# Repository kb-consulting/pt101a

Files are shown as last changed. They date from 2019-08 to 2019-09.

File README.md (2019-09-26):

# LPA96 - 96 Well Light Plate Apparatus (LPA) PCB
### Derived from original Tabor Lab designs from Rice University, with thermal and other improvements
This version uses a single blue LED for each of the 96 wells, and aims to solve the thermal problems with the TaborLab 96well design (dual LED per well), which was itself derived from the original 24well design (The latest 24well design has since diverged, to what is now available on GitHub).  
This version has been redesigned by Kevin Bibby (https://www.linkedin.com/in/kevinbibby/), commissioned by Dr Jenny Molloy - University of Cambridge / Cambridge Open Bioeconomy Lab.  
  
Original 24well article: https://www.nature.com/articles/srep35363  
Latest 24well Github (including chassis and other firmware files): https://github.com/taborlab/LPA-hardware  

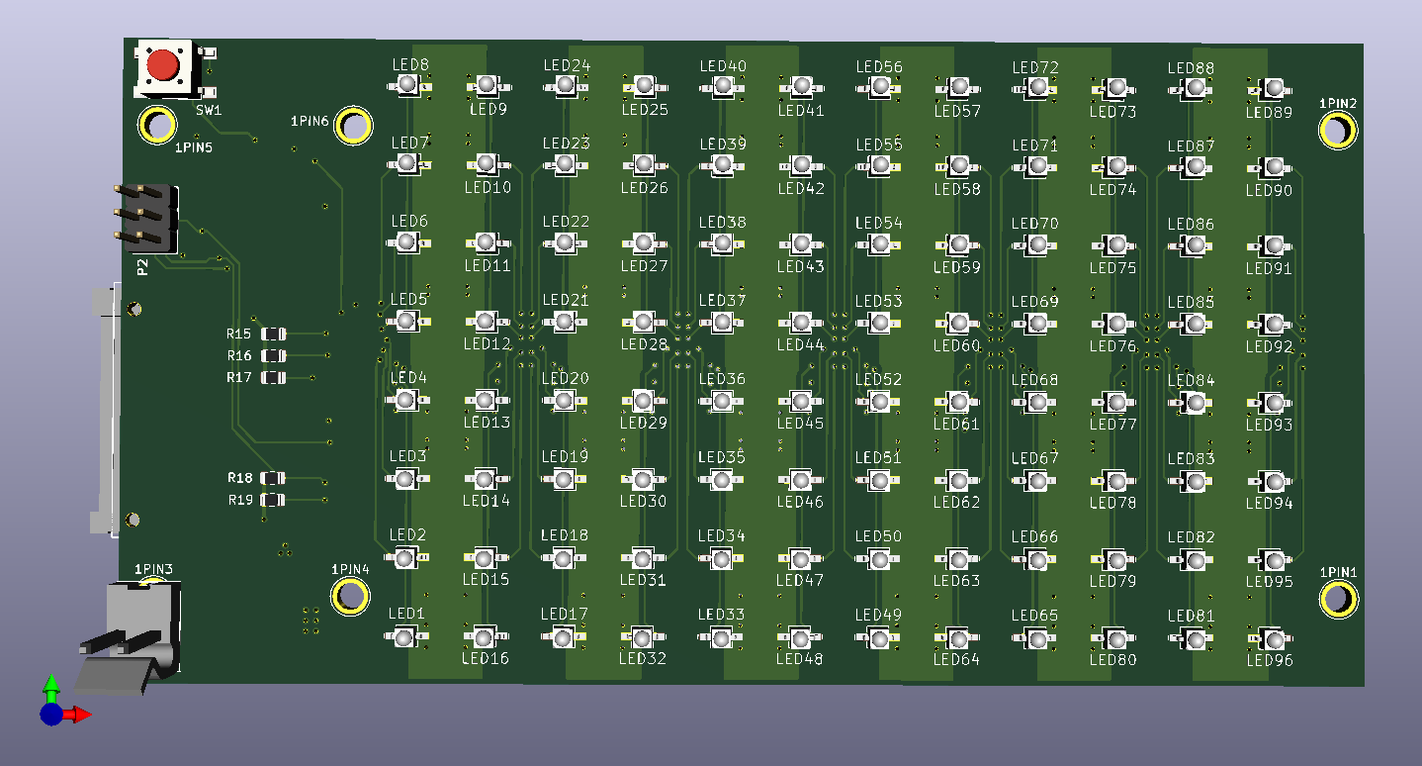
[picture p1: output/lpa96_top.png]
PCB TOP

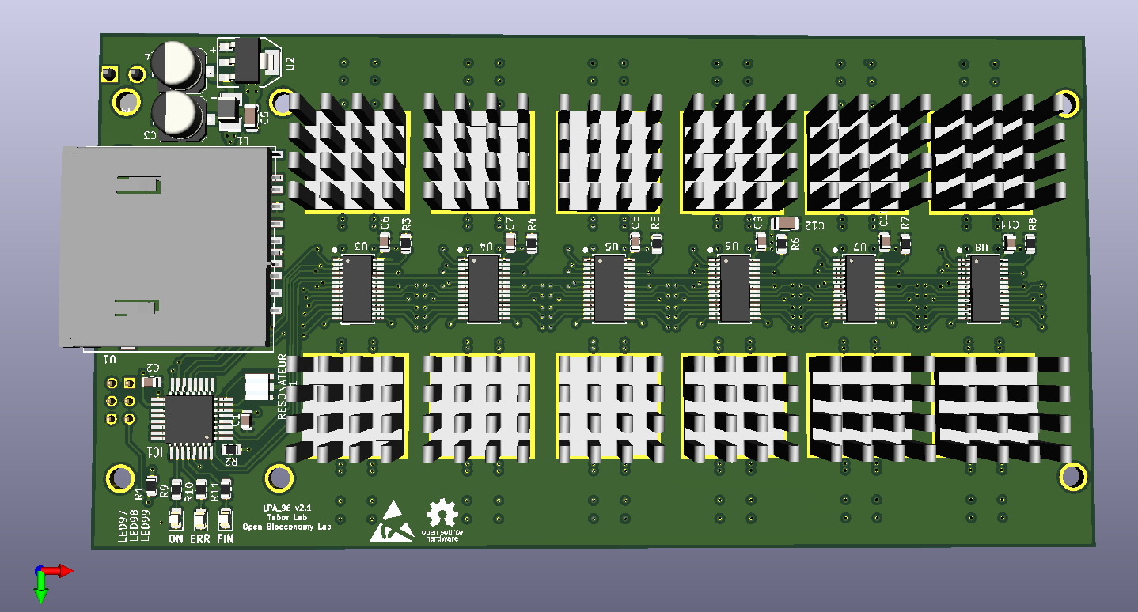
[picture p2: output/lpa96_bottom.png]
PCB BOTTOM


LPA96 v2.1  
05/09/2019 Kevin Bibby  
-------------------------
- Added all part info from original 24well LPA 'Nature' article (Supplementary Information, Table S1).
- Part info uses "Description", "Manufacturer1", "MPN1", "Vendor1" and "SKU1" part fields in KiCAD.
- Added files necessary to work with Kitspace.org for sharing the design and ordering parts easily.
- changed BOM info to reflect new LED chosen for this 96well version
- changed BOM info for C5,C12 - chosen part for new 1206 case size (was 0805 in v1.1).
- changed P2 to 2x3way exact part (2x3way) rather than 40way breakable header.
- changed R15-R19 from 50k to 47k to match part in BOM
- changed P1 and P2 library part 3D models to match part from BOM
- Note: P1 fouls on nearby hole, issue from original LPA96 design only just discovered after correct part info added
- Fixed U2 SOT223 3D model to use modern STEP model instead of old .wrl
- Updated footprints to use KiCAD5 latest (some changed since v2.0 e.g. rounded rectangle pads for commodity C / R footprints)

LPA96 v2.0  
22/08/2019 Kevin Bibby  
-------------------------
- changed to 4-layer PCB, and thermal improvements throughout, uses top planes and internal IN3 layer for VIN LED thermal dissipation, BOTTOM layer for GND LED driver IC dissipation
- changed from dual LEDs to single LEDs (VLDx1232G), and reduced the number of LED drivers accordingly from 12 to 6
- LED1-LED96 placed for zig-zag left-right pattern starting in bottom left of grid
- renamed all files from tca to lpa96, and set schematic/layout titleblocks accordingly incl author names
- resolved library issues and rescued parts, removed obsolete library parts - all parts are now either from default KiCAD5 libraries or from included project libraries
- fixed all ERC and DRC (Electrical/Design Rule Check) errors, through various means incl component/pin tweaks
- added 3D models for all parts (some estimates/representative due to source BOM not being available, P1 especially)
- added example 14x14x14mm heatsink footprint to library & STEP model and added to board to improve 3D CAD output / render
- renamed R_ON1,R_ERR1,R_FIN1 as R9,R10,R11 (best practice)
- renamed RESET1 as SW1 and ON1,ERR1,FIN1 as LED97,LED98,LED99 (best practice)
- changed C5 from 0805 to 1206 case size (better for 10uF), and added second of same bulk cap C12 for VCC on LED driver page, placed near LED drivers
- added OSHW and ESD logos to board
- moved P2 away from hole
- changed name of pin8/9 from "RSV" to DAT1/DAT2 to match datasheet of guessed part
- changed pin4 of regulator U2 manually to VCC net as symbol not made to include pin4
- added copper keepout around resonator Y1
- changed keepout near SDCARD to apply to copper planes too
- changed footprint for TLC5941 (downloaded from TI official, via ultralibrarian, generated for IPC 'most'), plus changed pin29 (pad) to be solid connection
- added pin29 for thermal pad to TLC5941 symbol (to match new footprint) and connected to GND
- changed via size from 0.889mm/0.653mm to 0.8mm/0.4mm , better annular ring margin and more space for routing while still being plenty manufacturable
- added soldermask 15mm squares to expose copper for 14mm heatsinks
- added heading/annotation text on schematic page

LPA96 v1.1 ?? (previously called 'TCA96')
-------------------------
Version received at handover. Had thermal issues to resolve and required a change of LEDs and reduction of driver ICs.

LPA96 v1.0 ??
-------------------------
??

 LPA96 / 'TCA96' previously derived from original 24-well version.

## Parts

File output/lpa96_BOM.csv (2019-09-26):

Source: | C:\freelance\git\pt101a\lpa96.sch
Date: | 05/09/2019 13:12:48
Tool: | Eeschema (5.1.4)-1
Generator: | C:\freelance\git\common-kicad/bom_csv_grouped_by_MPN.py
Component Count: | 141
Collated Components:
Item | Qty | Reference(s) | Value | Description | Manufacturer | MPN | Vendor | SKU | Symbol | Footprint | Datasheet
1 | 8 | C1, C2, C6, C7, C8, C9, C10, C11 | 100nF | -20/+80% 50V Y5V SMD MLCC Capacitor 0805 | Samsung | CL21F104ZBCNNNC | Digikey | 1276-1007-1-ND | Device:C | Capacitor_SMD:C_0805_2012Metric | ~
2 | 2 | C3, C4 | 47uF | 20% 35V SMD Electrolytic Capacitor | Nichicon | UWT1V470MCL1GS | Digikey | 493-2202-1-ND | Device:C | lpa96_footprints:CP_Elec_6.3x5.3 | ~
3 | 2 | C5, C12 | 10uF | 10% 25V X5R SMD MLCC Capacitor 1206 | Samsung | CL31A106KAHNNNE | Digikey | 1276-1075-1-ND | Device:C | Capacitor_SMD:C_1206_3216Metric | ~
4 | 1 | IC1 | ATMEGA328-A | AVR ATmega Microcontroller IC 8-Bit 20MHz | Microchip | ATMEGA328-AU | Digikey | ATMEGA328-AU-ND | lpa96_symbols:ATMEGA328-A | lpa96_footprints:TQFP32_FIXED
5 | 1 | L1 | 10uH | Wirewound Chip Inductor 900mA 1210 | Kemet | L1210R100MDWIT | Digikey | 399-9595-1-ND | Device:L | lpa96_footprints:L-1210 | ~
6 | 96 | LED1, LED2, LED3, LED4, LED5, LED6, LED7, LED8, LED9, LED10, LED11, LED12, LED13, LED14, LED15, LED16, LED17, LED18, LED19, LED20, LED21, LED22, LED23, LED24, LED25, LED26, LED27, LED28, LED29, LED30, LED31, LED32, LED33, LED34, LED35, LED36, LED37, LED38, LED39, LED40, LED41, LED42, LED43, LED44, LED45, LED46, LED47, LED48, LED49, LED50, LED51, LED52, LED53, LED54, LED55, LED56, LED57, LED58, LED59, LED60, LED61, LED62, LED63, LED64, LED65, LED66, LED67, LED68, LED69, LED70, LED71, LED72, LED73, LED74, LED75, LED76, LED77, LED78, LED79, LED80, LED81, LED82, LED83, LED84, LED85, LED86, LED87, LED88, LED89, LED90, LED91, LED92, LED93, LED94, LED95, LED96 | LED_ALT | Blue 465nm LED 3V 2-SMD, Gull Wing | Vishay | VLDB1232G-08 | Digikey | VLDB1232G-08CT-ND | Device:LED_ALT | lpa96_footprints:VLDx1232G | ~
7 | 1 | LED97 | LED_ALT | SMD LED Green 0805 | OSRAM | LG R971-KN-1 | Digikey | 475-1410-1-ND | Device:LED_ALT | LED_SMD:LED_0805_2012Metric | ~
8 | 1 | LED98 | LED_ALT | SMD LED Red 0805 | OSRAM | LH R974-LP-1 | Digikey | 475-1415-1-ND | Device:LED_ALT | LED_SMD:LED_0805_2012Metric | ~
9 | 1 | LED99 | LED_ALT | SMD LED Yellow 0805 | OSRAM | LY R976-PS-36 | Digikey | 475-2560-1-ND | Device:LED_ALT | LED_SMD:LED_0805_2012Metric | ~
10 | 1 | P1 | CONN_2 | Connector Male Through Hole 2 position 0.156" (3.96mm) | Molex | 0009652028 | Digikey | WM18823-ND | lpa96_symbols:CONN_2 | lpa96_footprints:PIN_ARRAY_2X1_3960um
11 | 1 | P2 | CONN_3X2 | Header Through Hole 2x3way 6 position 0.1" (2.54mm) | Amphenol ICC | 67997-206HLF | Digikey | 609-3234-ND | lpa96_symbols:CONN_3X2 | lpa96_footprints:pin_array_3x2
12 | 2 | R1, R2 | 10k | 5% Chip Resistor 0805 | Panasonic | ERJ-6GEYJ103V | Digikey | P10KACT-ND | Device:R | Resistor_SMD:R_0805_2012Metric | ~
13 | 6 | R3, R4, R5, R6, R7, R8 | 2.2k | 0.5% Chip Resistor 0805 | Susumu | RR1220P-222-D | Digikey | RR12P2.2KDCT-ND | Device:R | Resistor_SMD:R_0805_2012Metric | ~
14 | 3 | R9, R10, R11 | 330R | 5% Chip Resistor 0805 | Samsung | RC2012J331CS | Digikey | 1276-5519-1-ND | Device:R | Resistor_SMD:R_0805_2012Metric | ~
15 | 5 | R15, R16, R17, R18, R19 | 47k | 5% Chip Resistor 0805 | Panasonic | ERJ-6GEYJ473V | Digikey | P47KACT-ND | Device:R | Resistor_SMD:R_0805_2012Metric | ~
16 | 1 | SW1 | SW_PUSH | SPST-NO Top Activated SMD Tactile Switch | C&K | PTS645SK43SMTR92 LFS | Digikey | CKN9084CT-ND | lpa96_symbols:SW_PUSH | lpa96_footprints:SW_PUSH_SMD | ~
17 | 1 | U1 | SD_CARD | 9 Position Connector SD Card, Surface Mount, Right Angle | Amphenol ICC | 101-00313-68-02 | Digikey | 101-00313-68-02CT-ND | lpa96_symbols:SD_CARD | lpa96_footprints:SD_CONN
18 | 1 | U2 | LD1117S33 | IC Linear Regulator 3.3V 800mA SOT-223 | ST Microelectronics | LD1117S33TR | Digikey | 497-1242-1-ND | lpa96_symbols:LD1117S50 | lpa96_footprints:SOT223 | ~
19 | 6 | U3, U4, U5, U6, U7, U8 | TLC5941 | LED Driver IC 16 Output 28-HTSSOP | Texas Instruments | TLC5941PWP | Digikey | 296-18617-5-ND | lpa96_symbols:TLC5941 | lpa96_footprints:TLC5941_PWP_28 | DOCUMENTATION
20 | 1 | Y1 | RESONATEUR | 16MHz Ceramic Resonator SMD | Abracon | AWSCR-16.00CV-T | Digikey | 535-10008-1-ND | lpa96_symbols:RESONATEUR | lpa96_footprints:crystal_smd

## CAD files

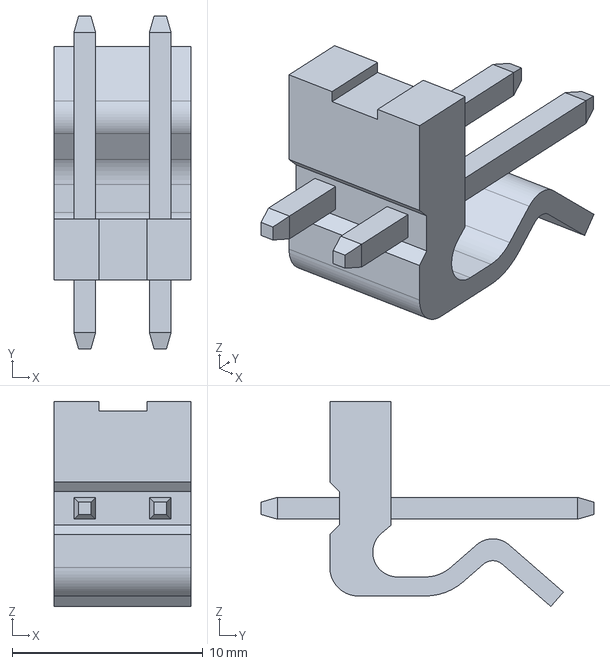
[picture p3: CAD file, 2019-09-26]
footprints/3d-models/Molex_009652028.stp
7.16 x 17.4 x 10.8 mm

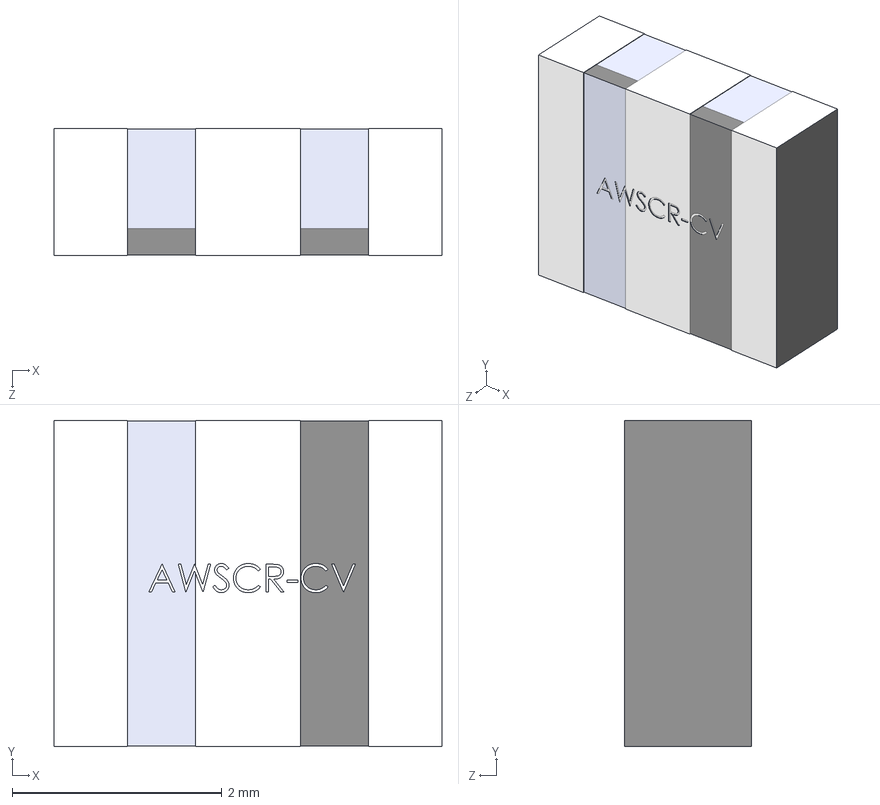
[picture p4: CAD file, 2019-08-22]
footprints/3d-models/example_resonator.step
3.70 x 3.11 x 1.21 mm

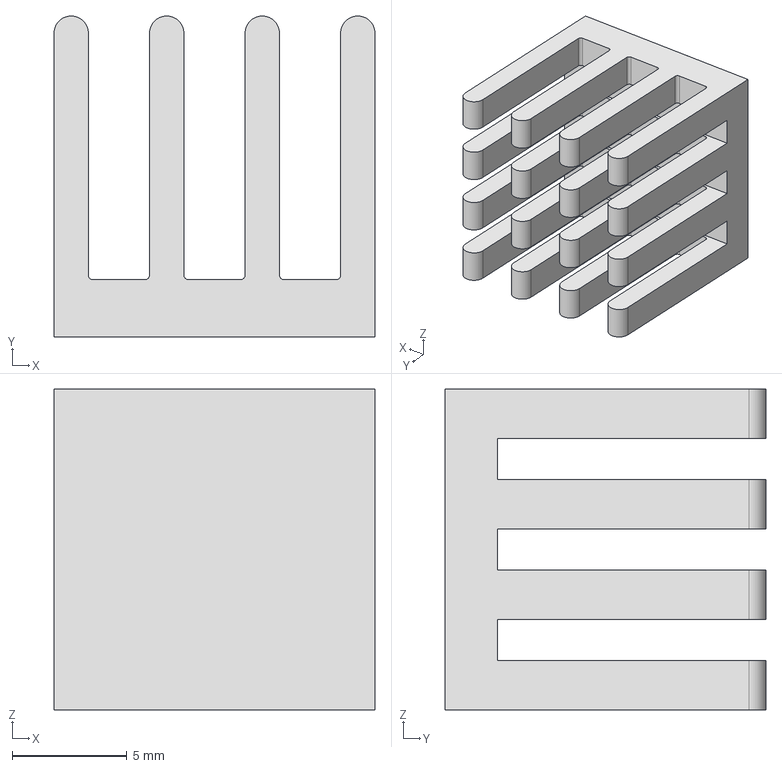
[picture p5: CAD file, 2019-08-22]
footprints/3d-models/example_heatsink_14x14x14mm.stp
14.0 x 14.0 x 14.0 mm

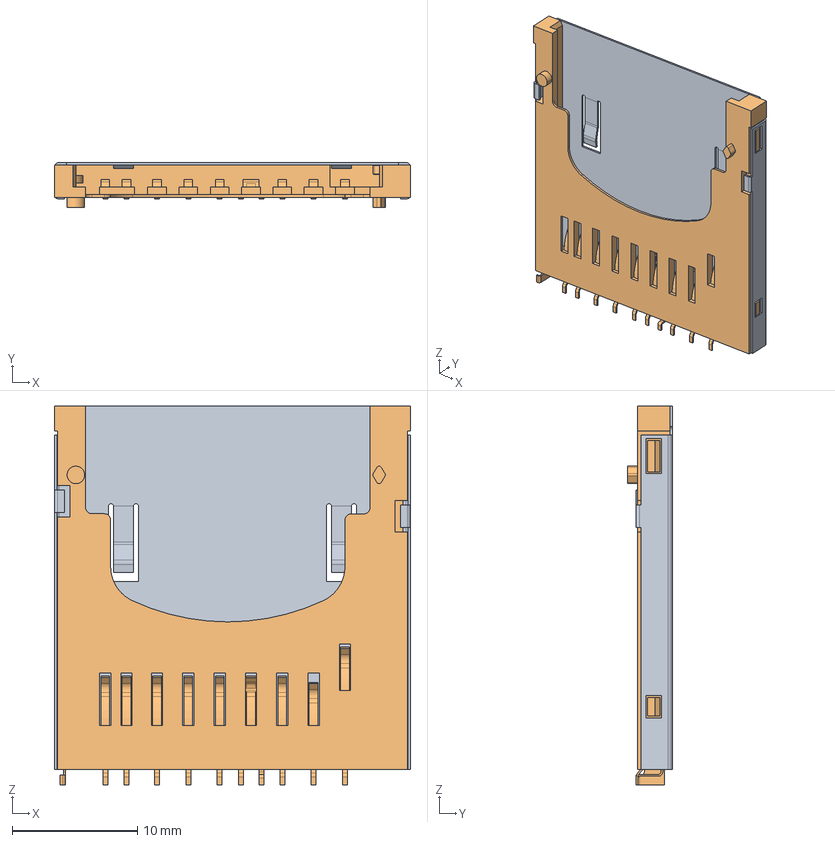
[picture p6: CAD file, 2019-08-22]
footprints/3d-models/SD_card_reader_10067847-001RLF.step
28.4 x 3.60 x 30.3 mm
PRT0003
PRT0005

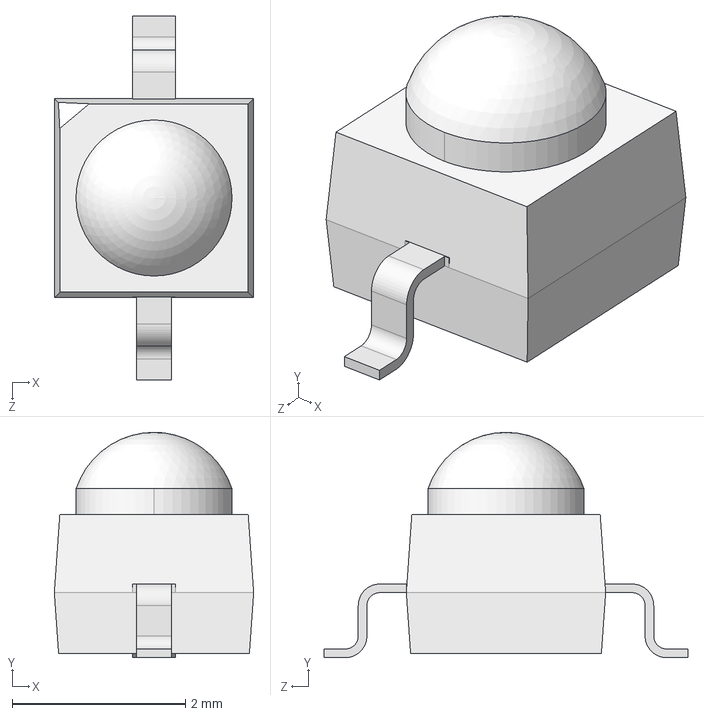
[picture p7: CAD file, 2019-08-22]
footprints/3d-models/smd_led_VLDx1535G.step
2.30 x 2.60 x 4.20 mm

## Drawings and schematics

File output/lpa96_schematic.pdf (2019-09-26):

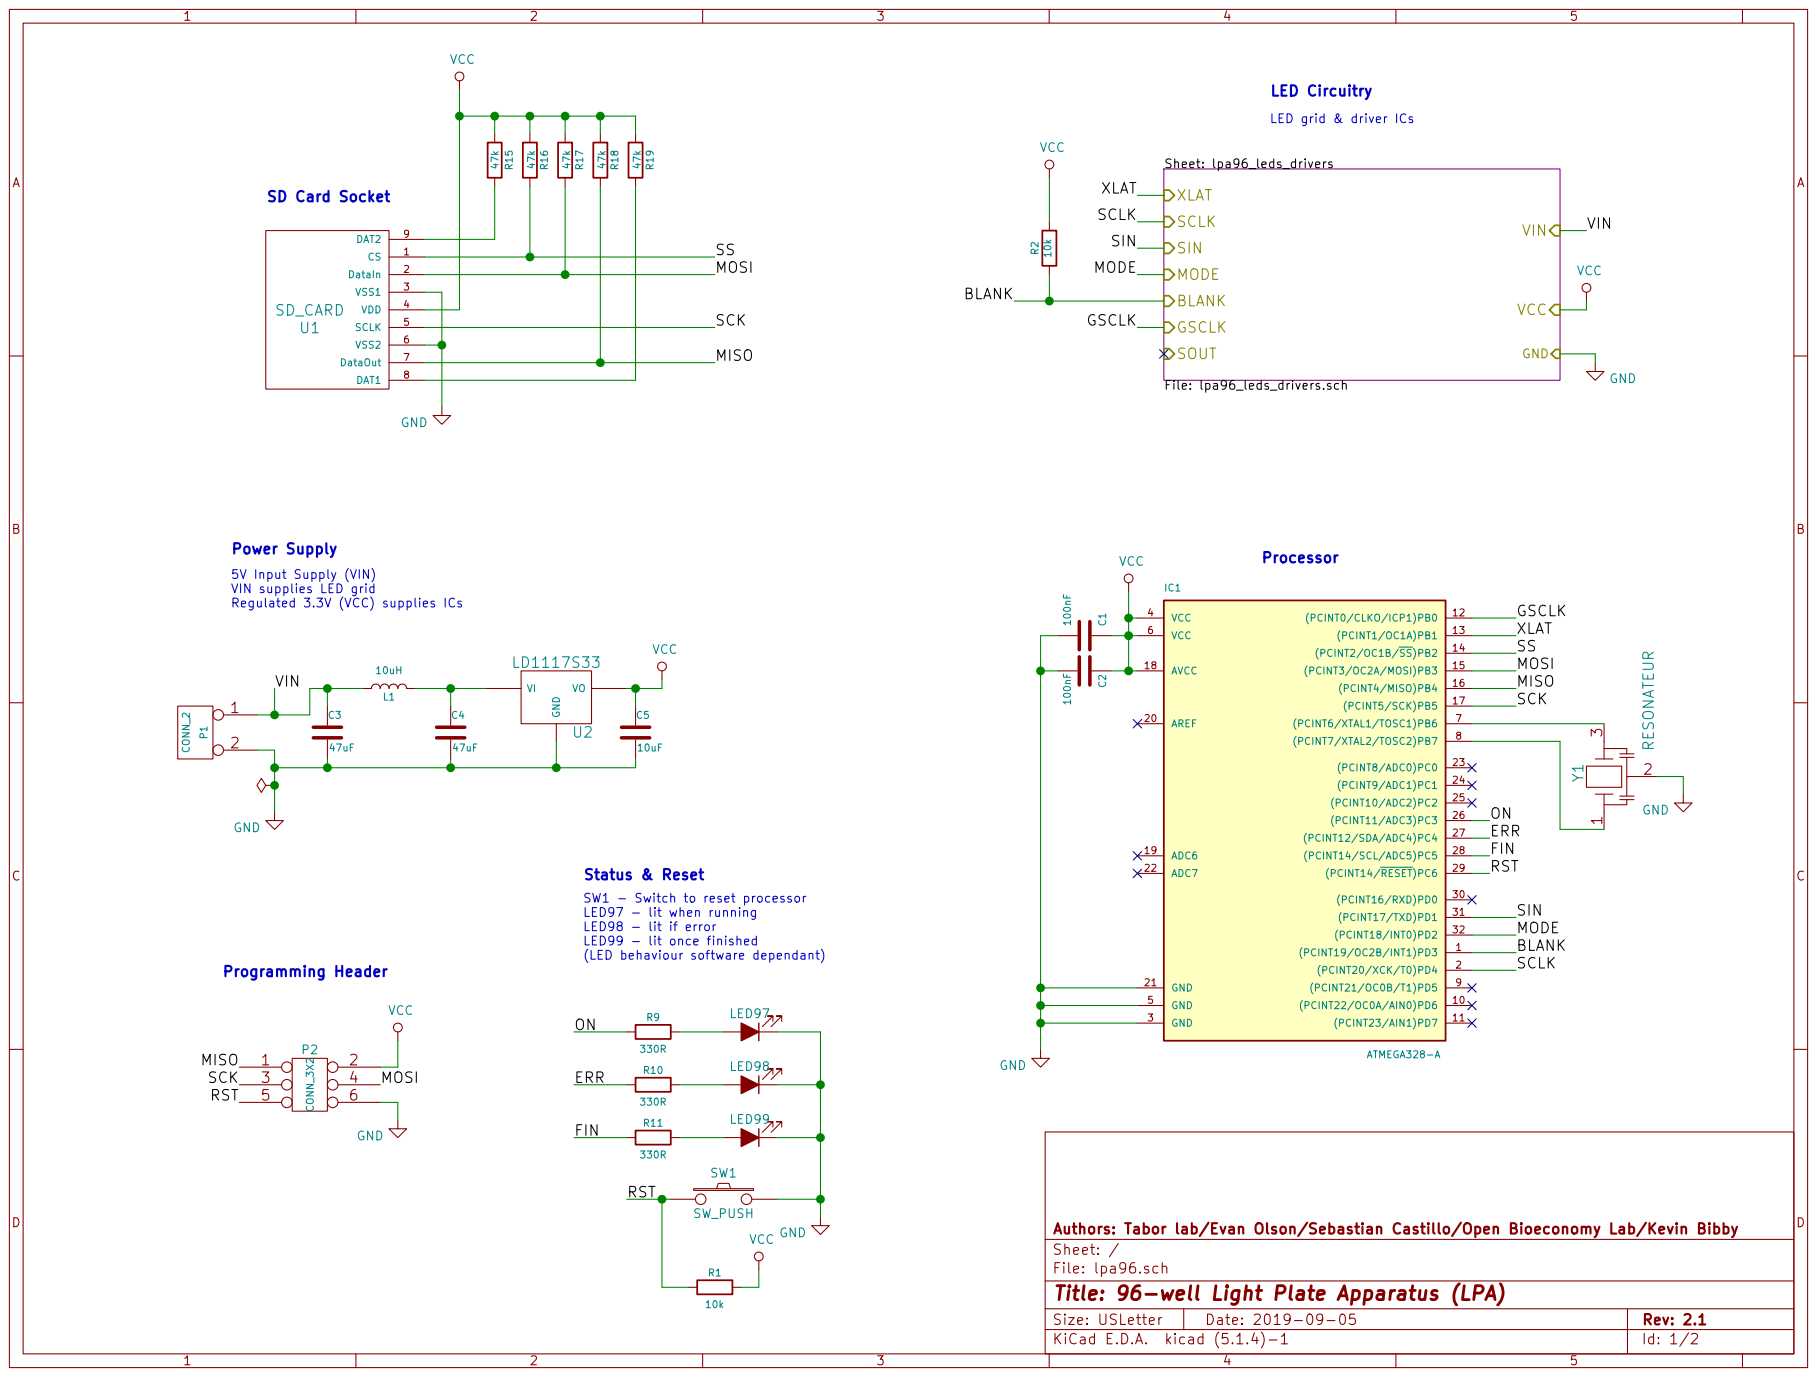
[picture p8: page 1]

LED grid & driver ICs Processor SW1 - Switch to reset processor

File: lpa96_leds_drivers.sch XLAT SCLK

Power Supply
5V Input Supply (VIN)
VIN supplies LED grid

LED97 - lit when running
LED98 - lit if error LED99 - lit once finished

(LED behaviour software dependant)

File: lpa96.sch Sheet: / Authors: Tabor lab/Evan Olson/Sebastian Castillo/Open Bioeconomy Lab/Kevin Bibby

Id: 1/2 Title: 96-well Light Plate Apparatus (LPA)

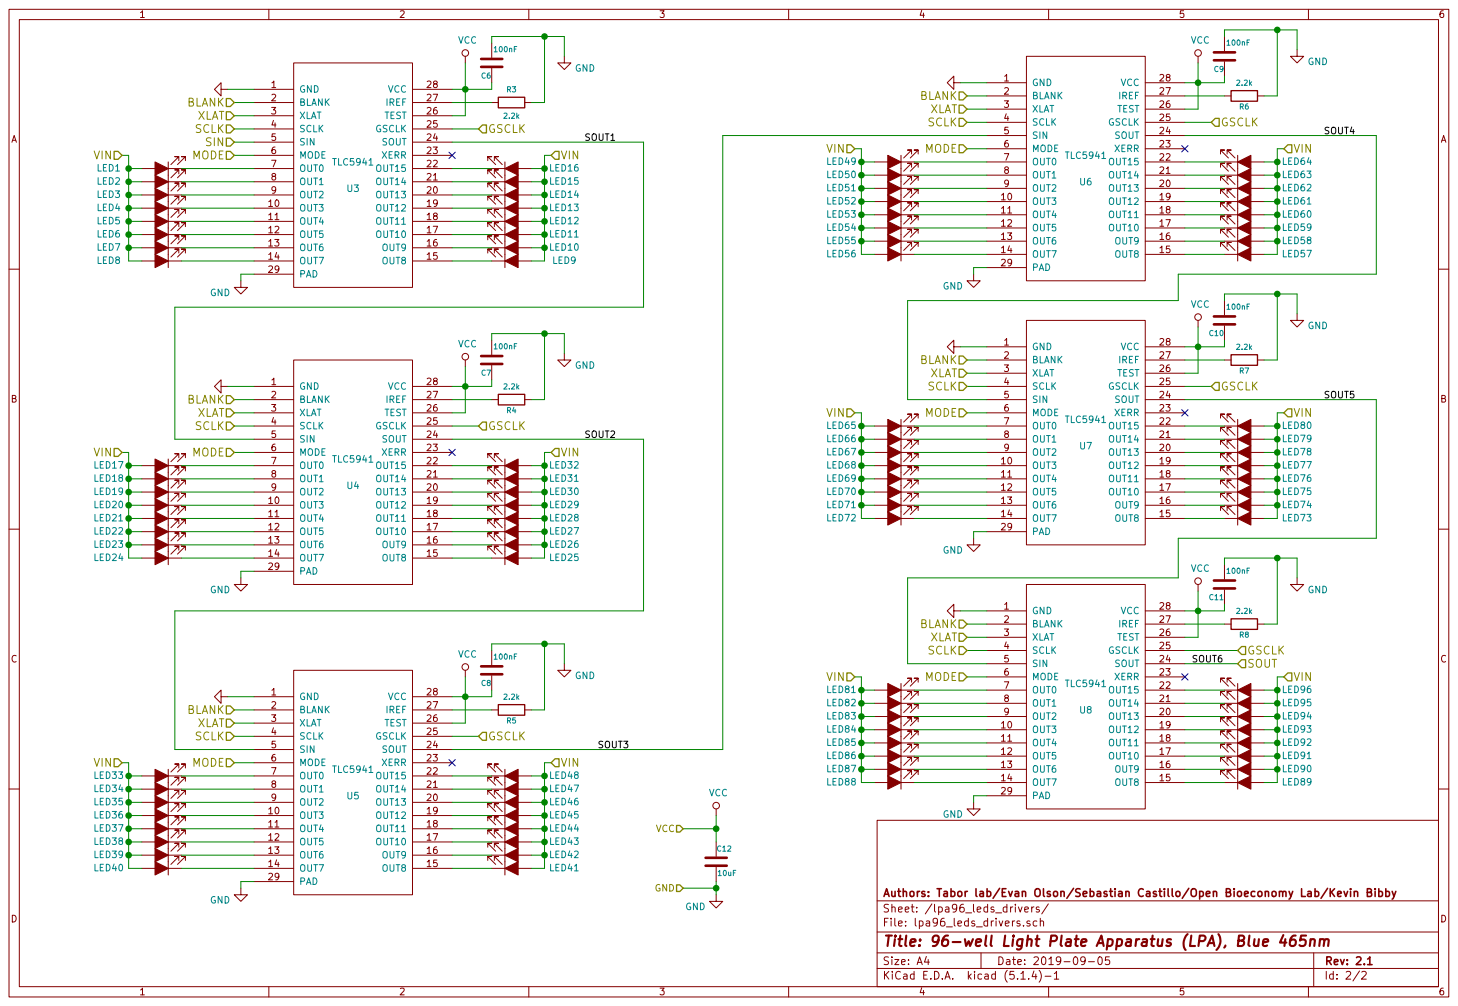
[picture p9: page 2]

Authors: Tabor lab/Evan Olson/Sebastian Castillo/Open Bioeconomy Lab/Kevin Bibby
Sheet: /lpa96_leds_drivers/
File: lpa96_leds_drivers.sch
Id: 2/2 Title: 96-well Light Plate Apparatus (LPA), Blue 465nm

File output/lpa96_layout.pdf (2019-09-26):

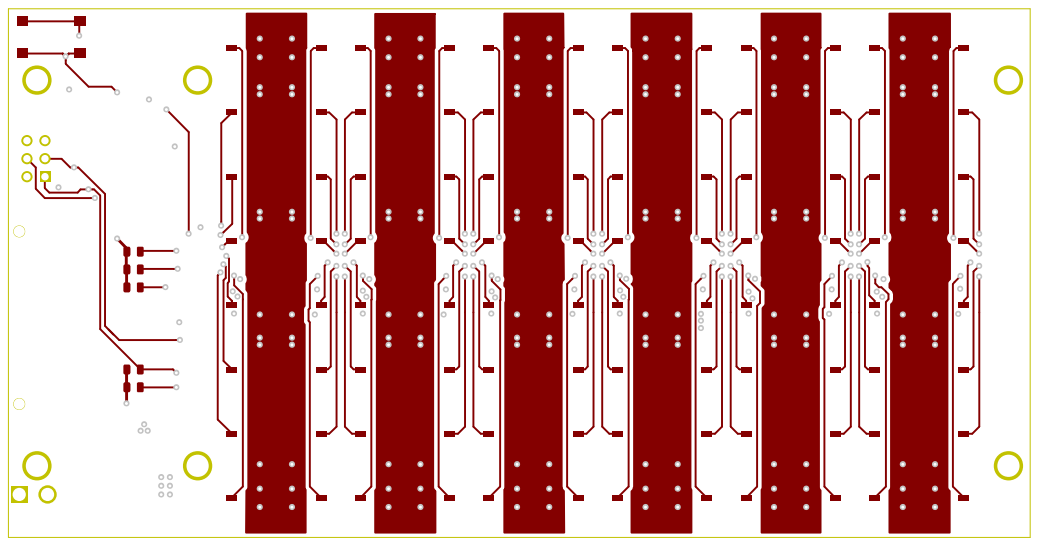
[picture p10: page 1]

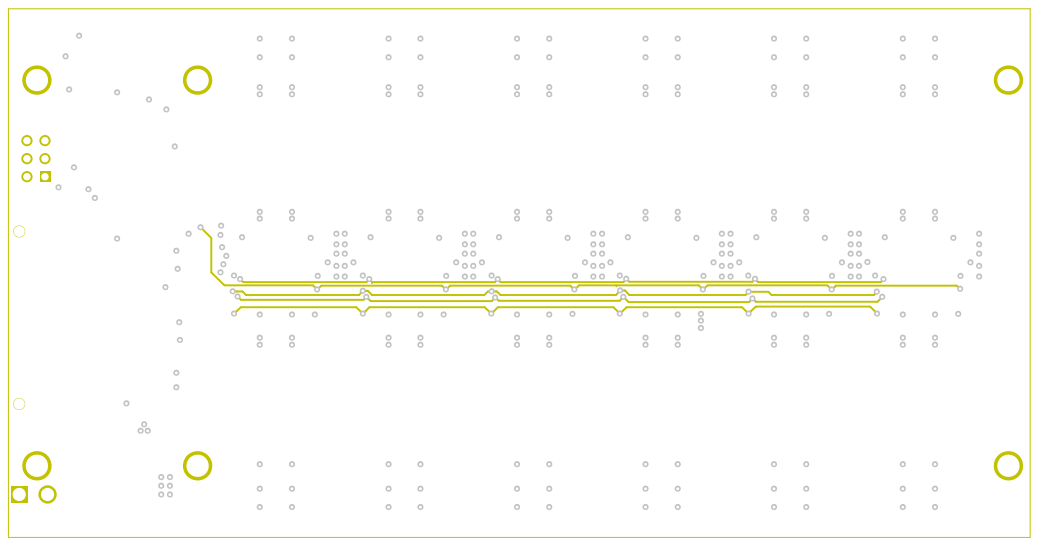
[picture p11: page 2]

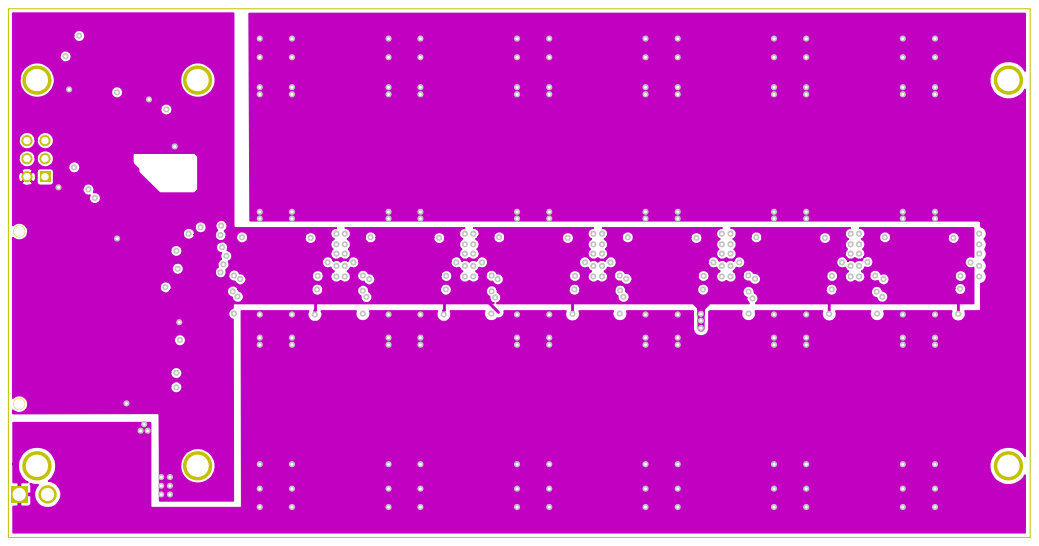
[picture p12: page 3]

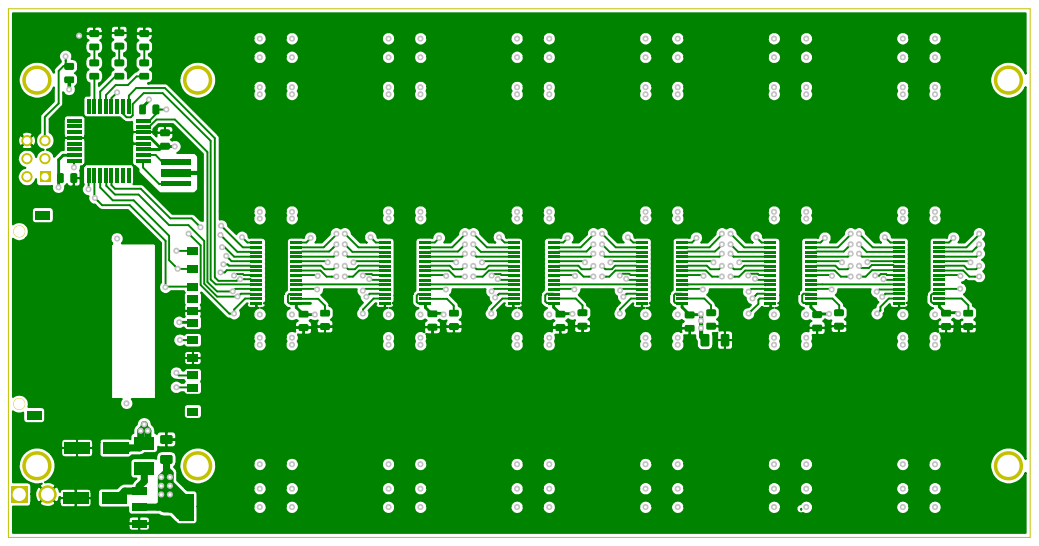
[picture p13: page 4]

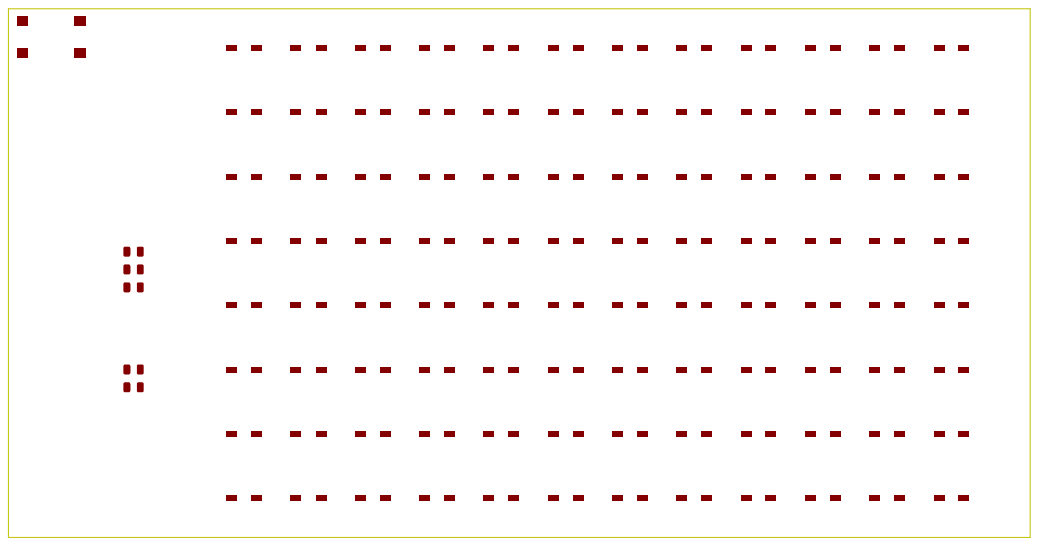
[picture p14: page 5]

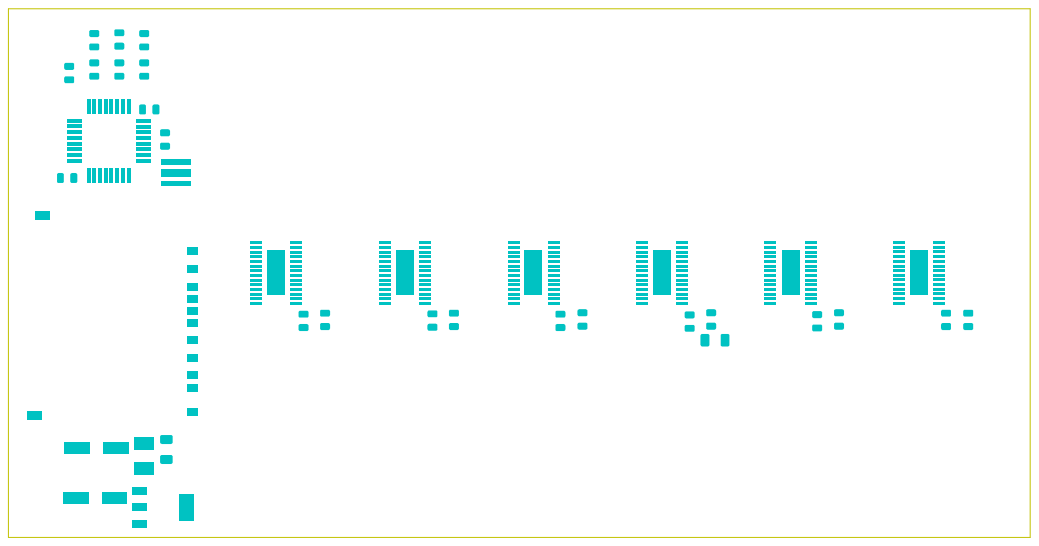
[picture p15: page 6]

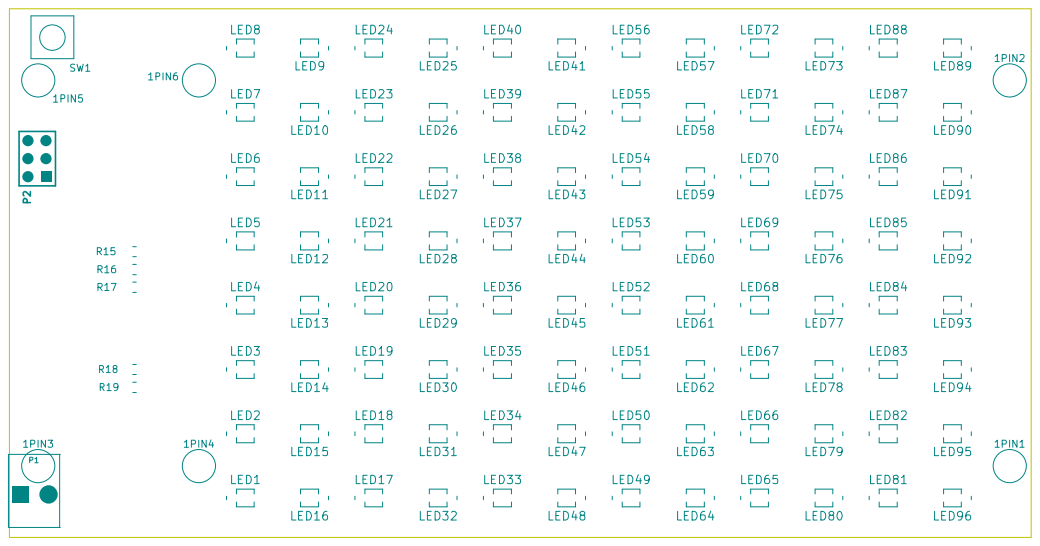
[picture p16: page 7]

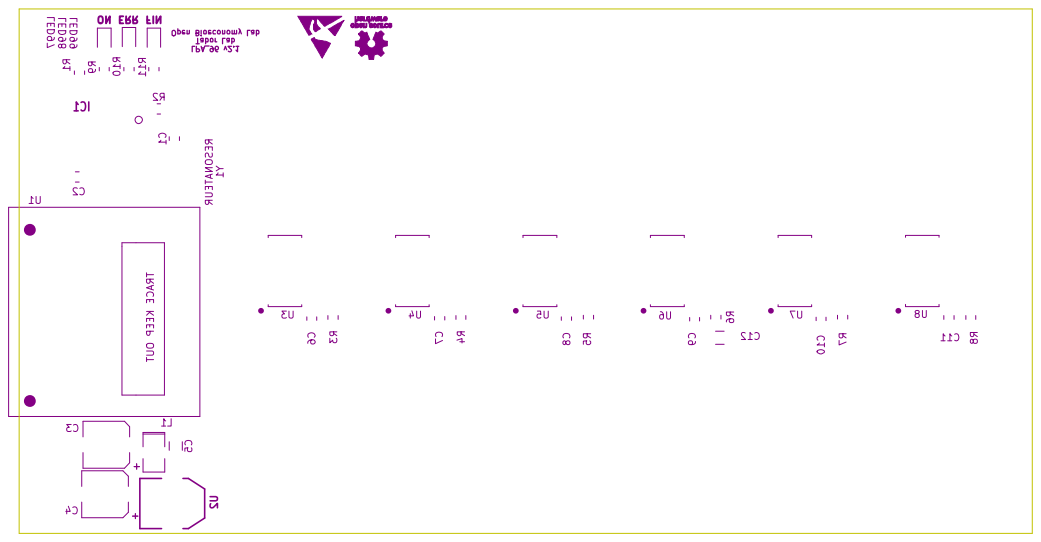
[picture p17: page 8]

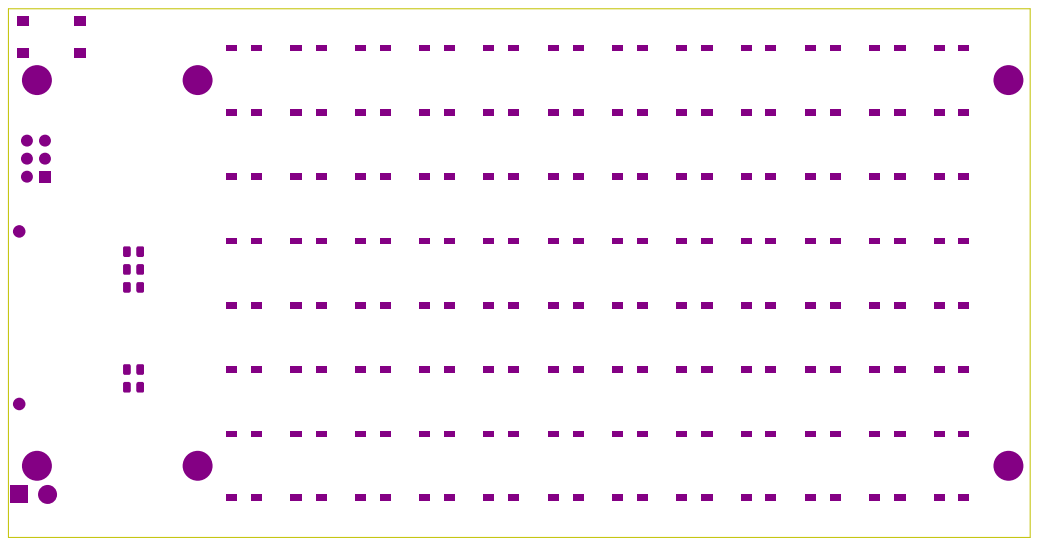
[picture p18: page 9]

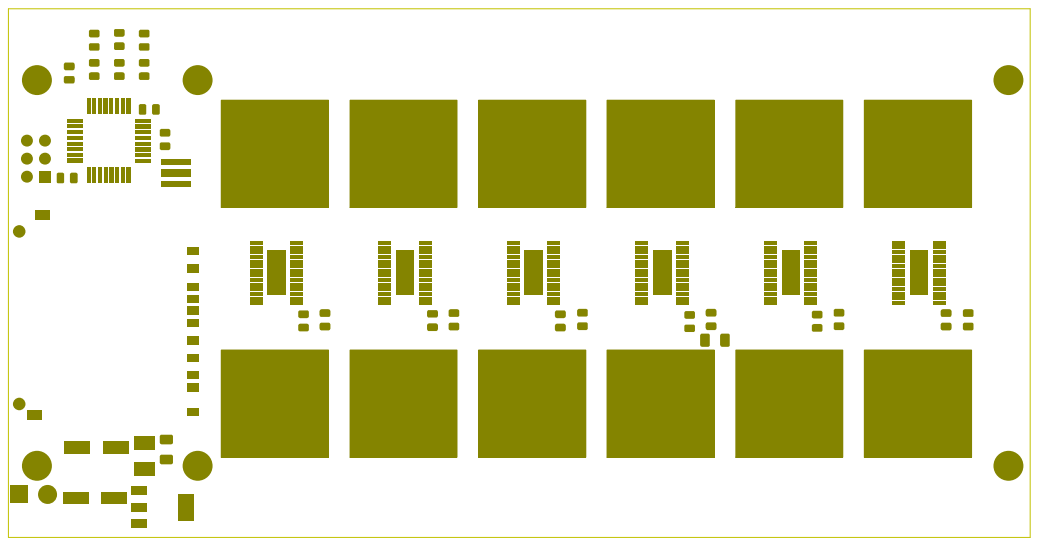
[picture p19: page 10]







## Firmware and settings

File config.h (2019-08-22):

/*
 * config.h
 *
 * Created: 03/03/2014 02:29:05 PM
 *  Author: Sebastian Castillo
 */

// Global configuration variables
#define F_CPU 16000000UL

// Configuration for Tlc5941 module
#define Tlc5941_GSCLK_DDR DDRB
#define Tlc5941_GSCLK_PORT PORTB
#define Tlc5941_GSCLK_PIN PB0

#define Tlc5941_XLAT_DDR DDRB
#define Tlc5941_XLAT_PORT PORTB
#define Tlc5941_XLAT_PIN PB1

#define Tlc5941_SIN_DDR DDRD
#define Tlc5941_SIN_PORT PORTD
#define Tlc5941_SIN_PIN PD1

#define Tlc5941_MODE_DDR DDRD
#define Tlc5941_MODE_PORT PORTD
#define Tlc5941_MODE_PIN PD2

#define Tlc5941_BLANK_DDR DDRD
#define Tlc5941_BLANK_PORT PORTD
#define Tlc5941_BLANK_PIN PD3

#define Tlc5941_SCLK_DDR DDRD
#define Tlc5941_SCLK_PORT PORTD
#define Tlc5941_SCLK_PIN PD4

#define Tlc5941_TIMER 2

#define Tlc5941_USART_SPI 1

#define Tlc5941_N 6

#define Tlc5941_MANUAL_DC_FUNCS 1

#include <avr/io.h>
#include <avr/pgmspace.h>
#include "Tlc5941/Tlc5941.h"

/* definition for unknown earlier 96well design */
static const Tlc5941_gsData_t well2channel[Tlc5941_numChannels] = {
	0, 1, 2, 3, 4, 5, 6, 7, 8, 9, 10, 11,
	12, 13, 14, 15, 16, 17, 18, 19, 20, 21, 22, 23,
	24, 25, 26, 27, 28, 29, 30, 31, 32, 33, 34, 35,
	36, 37, 38, 39, 40, 41, 42, 43, 44, 45, 46, 47,
	48, 49, 50, 51, 52, 53, 54, 55, 56, 57, 58, 59,
	60, 61, 62, 63, 64, 65, 66, 67, 68, 69, 70, 71,
	72, 73, 74, 75, 76, 77, 78, 79, 80, 81, 82, 83,
	84, 85, 86, 87, 88, 89, 90, 91, 92, 93, 94, 95,
	96, 97, 98, 99, 100, 101, 102, 103, 104, 105, 106, 107,
	108, 109, 110, 111, 112, 113, 114, 115, 116, 117, 118, 119,
	120, 121, 122, 123, 124, 125, 126, 127, 128, 129, 130, 131,
	132, 133, 134, 135, 136, 137, 138, 139, 140, 141, 142, 143,
	144, 145, 146, 147, 148, 149, 150, 151, 152, 153, 154, 155,
	156, 157, 158, 159, 160, 161, 162, 163, 164, 165, 166, 167,
	168, 169, 170, 171, 172, 173, 174, 175, 176, 177, 178, 179,
	180, 181, 182, 183, 184, 185, 186, 187, 188, 189, 190, 191};*/

/* definition for LPA96 v1.1 (96-well double-LED)
static const Tlc5941_gsData_t well2channel[Tlc5941_numChannels] PROGMEM = {
	95, 94, 81, 80, 79, 78, 65, 64, 63, 62, 49, 48, 47, 46, 33, 32, 31, 30, 17, 16, 15, 14, 1, 0,
	93, 92, 83, 82, 77, 76, 67, 66, 61, 60, 51, 50, 45, 44, 35, 34, 29, 28, 19, 18, 13, 12, 3, 2,
	91, 90, 85, 84, 75, 74, 69, 68, 59, 58, 53, 52, 43, 42, 37, 36, 27, 26, 21, 20, 11, 10, 5, 4,
	89, 88, 87, 86, 73, 72, 71, 70, 57, 56, 55, 54, 41, 40, 39, 38, 25, 24, 23, 22, 9, 8, 7, 6,
	103, 102, 105, 104, 119, 118, 121, 120, 135, 134, 137, 136, 151, 150, 153, 152, 167, 166, 169, 168, 183, 182, 185, 184,
	101, 100, 107, 106, 117, 116, 123, 122, 133, 132, 139, 138, 149, 148, 155, 154, 165, 164, 171, 170, 181, 180, 187, 186,
	99, 98, 109, 108, 115, 114, 125, 124, 131, 130, 141, 140, 147, 146, 157, 156, 163, 162, 173, 172, 179, 178, 189, 188,
	97, 96, 111, 110, 113, 112, 127, 126, 129, 128, 143, 142, 145, 144, 159, 158, 161, 160, 175, 174, 177, 176, 191, 190,};
    */
    
/* definition for LPA96 v2.0 (96-well single-LED) */
static const Tlc5941_gsData_t well2channel[Tlc5941_numChannels] PROGMEM = {
	7,8,23,24,39,40,55,56,71,72,87,88,
    6,9,22,25,38,41,54,57,70,73,86,89,
    5,10,21,26,37,42,53,58,69,74,85,90,
    4,11,20,27,36,43,52,59,68,75,84,91,
    3,12,19,28,35,44,51,60,67,76,83,92,
    2,13,18,29,34,45,50,61,66,77,82,93,
    1,14,17,30,33,46,49,62,65,78,81,94,
    0,15,16,31,32,47,48,63,64,79,80,95
    };

// Time step scaling
#define stepSizeScaling 1.0

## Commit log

2019-08-19 added initial files from client
    files taken from Google Drive location given for handover
    [tca-2019-07-17-10-12-58.sch, tca.kicad_pcb, tca.sch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]
2019-08-19 opened in KiCAD 5.1.4 and went through rescue process
    seems to have moved all parts to tca-rescue lib, updated EESchema Library version and removed references to default libs. OK for now so can work on, may adjust libraries later. not committed 'rescue-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
    [tca.sch, tlcs_1-6.sch, tlcs_7-12.sch]
2019-08-19 reduce number of drivers, fix some ERCs
    deleted heirarchical block for second set of drivers/LEDs (reduce from 12 to 6), and deleted source schematic tlcs_7-12.sch
    fixed pin types on part TLC5941 (TEST, GSCLK now input, IREF now bidirectional) so they match datasheet and resolves lots of ERCs
    [tca.sch, tlcs_1-6.sch, tlcs_7-12.sch]
2019-08-19 corrected resistor footprints. cleaning layout, ready for new LED type.
    corrected R15-R19 to use same footprint as other resistors (was undefined)
    cleaned layout after removing driver ICs last commit
    moved remaining drivers off board for initial placement
    cleaned all vias/tracks in central LED area, will layout again
    removed bottom half of LEDs (will need moving/adding once changed from double to single LED footprint type)
    [tca.kicad_pcb, tca.sch]
2019-08-19 partially changed LEDs
    done new footprint, added to new tca_footprints.pretty library. partially changed LEDs in schematic.
    committing to go back and double check previous LED order to maintain firmware compatibility.
    added /rescue-backup/ to git ignore (dont need with version control)
    [tca.kicad_pcb, tca.sch, tlcs_1-6.sch]
2019-08-19 finished changing all LEDs
    LED1-LED96 added and referenced to match schematic, for zig-zag left-right pattern starting in bottom left of grid
    arranged with VIN facing back-to-back so can have columns of VIN copper shape going vertically, to fit in with LED routing also on top
    [tca.kicad_pcb, tlcs_1-6.sch]
2019-08-19 design rules & annotation text
    adjusted design rules: 0.25/0.2mm track/gap (larger for power nets), via 0.9/0.5mm (smaller 0.6/0.25mm for thermal vias), 0.05mm solder mask clearance
    replaced all vias with 0.9/0.5mm by default, this and design rules should solve most of DRC issues
    added some common track widths
    placed driver chips and routed some important nets & surrounding passives first
    neatened placement on schematic page and added heading text for each are
    deleted duplicate Edge.cuts line on right side of board which was causing DRC, not sure whether I introduced or existing
    [tca.kicad_pcb, tca.sch, tlcs_1-6.sch]
2019-08-19 change to 4-layer, footprint changes, added thermal planes
    changed to 4-layer PCB, use internal layer3 for VIN thermal dissipation, bottom layer for GND driver IC dissipation
    changed chip CMD resistors & capacitors to use updated library footprints
    changed C5 from 0805 to 1206 size (better for 10uF) - needs new BOM part choosing
    set up bottom GND copper shape to fill whole board, and added thermal relief (will need to remove for driver IC pads)
    added top VIN copper for LEDs (no thermal relief) and vias to connect to layer3 plane
    [tca.kicad_pcb, tca.sch, tlcs_1-6.sch]
2019-08-19 finished bulk of LED routing, started power routing
    done VCC and VIN planes and connected some vias
    finished the bulk of the LED routing work, still middle signals to connect
    minor text note change and track width addition
    [tca.kicad_pcb, tca.sch]
2019-08-20 updating footprints & 3d models, adding heatsink exposed copper squares
    changed LEDs ERR1 FIN1 ON1 from CM0805 to LEDs:LED_0805 from new KiCAD libraries
    added soldermask 15mm squares to expose copper for 14mm heatsinks, moved VIN thermal vias outside of these areas
    added LED 3D model for VLDx1232G, from VLDx1535G (very similar package) downloaded from grabcad.com designed by 'thmjpr'
    set U5 LED driver 3D model - using HTSSOP-28-1EP model in default Kicad libraries, need to confirm if this is OK and how to get on all parts given this is old cached library part
    [smd_led_VLDx1535G.STEP, tca.kicad_pcb, tca.sch]
2019-08-20 changed via sizes, routed more signals
    removed 0.5/0.25mm via size (won't use), single remaining via size reduced to 0.8mm/0.4mm , makes routing easier and still relatively large
    done remaining driver IC fanout for common signals, started routing some on IN1 layer
    [tca.kicad_pcb]
2019-08-21 symbol & footprint library changes, plus LED driver signal routing
    done some more routing of central LED driver signals on IN1 layer
    created new 'lpa96_symbols.lib' schematic library and moved existing symbols from tca-rescue to there (except commodity ones, will take from main KiCAD library)
    changed footprint for TLC5941 (downloaded from TI official, via ultralibrarian, generated for IPC 'most'), still needs some tweaks
    added pin29 for thermal pad to TLC5941 symbol (to match new footprint), needs connecting in schematic still
    deleted obsolete .mod footprint files, and also double_led, myParts, Resonator_3pins and Cer_reso symbol libraries (old parts no longer used, or now in new lpa96_symbo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
    [tca.kicad_pcb, tca.sch, tlcs_1-6.sch]
2019-08-21 power supply improvements & routing, footprint and other tweaks
    added extra bulk cap C12 for VCC on LED driver page, placed near LED drivers
    connected pin29 of new TLC5941 symbol to GND and changed pad to be solid connection to plane
    finished placement of decoupling caps near drivers, and VCC routing/plane/vias for drivers
    small thermal via tweaks
    changed keepout near SDCARD to apply to copper planes too
    finished the routing around input and regulator
    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
    [tca.kicad_pcb, tlcs_1-6.sch]
2019-08-21 final routing, resolving DRCs, and added 3D models
    done last few signals final routing to the processor
    deleted crosshair centre in VLDx1232G footprint as it was causing DRC errors, DRC errors now all cleared
    added copper keepout around resonator Y1
    added example 14x14x14mm heatsink footprint to library & STEP model and added to board to improve 3D CAD output / render
    added 3D model (from KiCAD library) for processor
    [SD_card_reader_10067847-001RLF.step, example_heatsink_14x14x14mm.stp, tca.kicad_pcb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]
2019-08-21 renamed refdes for some parts, library changes, adding 3d models
    renamed library, both folder and the reference in KiCAD to remove old 'tca' reference, updated other references to match
    added 3d models for input caps and reset switch from KiCad main library (locally in design)
    changed all resistors and GNDs to use symbols from main KiCAD library
    renamed R_ON1,R_ERR1,R_FIN1 as R9,R10,R11 (best practice)
    renamed RESET1 as SW1 and ON1,ERR1,FIN1 as LED97,LED98,LED99 (best practice)
    [SD_card_reader_10067847-001RLF.step, example_heatsink_14x14x14mm.stp, smd_led_VLDx1535G.step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]
2019-08-21 updated some footprints symbols etc
    updated to text to match last commit
    changed input inductor to use symbol/footprint/3dmodel from main KiCAD library
    changed input capacitors to use symbol/footprint/3dmodel from main KiCAD library
    [tca.kicad_pcb, tca.sch]
2019-08-21 library work, connect regulator VCC, change value of decoupling caps to be in terms of nF
    changed all 0.1uF caps to be 100nF (same, but more common expression)
    set pin4 of regulator to be VCC and connected up (can't be sure without source BOM, but think pin2 is NC and footprint/symbol has been done poorly
    move all remaining grounds and capacitors to use main KiCAD library symbols, and deleted all remnants of rescue library
    exported all remaining footprints from PCB and put in footprint library, and changed footprint references to point there so now all valid
    also copied input capacitor footprint to library so I can customise with correct 3D model
    changed input inductor footprint (realised pr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
    [example_resonator.step, tca-2019-07-17-10-12-58.sch, tca.kicad_pcb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]
2019-08-21 renamed project, programming header move and added 3d model
    added 3d model for programming header P2
    moved P2 away from hole
    renamed all files from tca to lpa96 as agreed
    [lpa96.kicad_pcb, lpa96.sch, lpa96_leds_drivers.sch]
2019-08-21 fix ERC errors, added last 3d model, other misc
    changed TLC5941 pin29 pad to 'passive' type to fix ERC error
    added PWR_FLAG special symbol on to input GND to fix ERC error
    changed all VCC to proper power symbol instead of net alias
    connected shield tabs of SDCARD footprint to GND (symbol doesn't have a pin)
    changed SD_CARD symbol for pin8/9 are passive instead of NC (avoids ERCs)
    changed name of pin8/9 from "RSV" to DAT1/DAT2 to match datasheet of guessed part
    changed pin4 of regulator back to VCC (got messed up after change to VCC power symbols instead of net alias
    added 3d model to P1 (revise after BOM received)
    [lpa96.kicad_pcb, lpa96.sch, lpa96_leds_drivers.sch]
2019-08-21 done titleblocks, added silkscreen logos
    added OSHW and ESD logos to board
    filled in titleblocks with title, revision, date, authors
    [lpa96.kicad_pcb, lpa96.sch, lpa96_leds_drivers.sch]
2019-08-22 title name change, exported final design pack
    changed titleblock to remove "blue 465nm" to keep general, removed TODO text ready for export
    added full export of design pack (schematic/layout pdfs, step model, gerbers, position & drill files)
    [lpa96-B_Cu.gbr, lpa96-B_Fab.gbr, lpa96-B_Mask.gbr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]
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2019-08-22 added BOM (incomplete, pending missing source data) and config.h for this version
    [lpa96_BOM.xlsx]
2019-09-03 small tweaks, added component part numbers & descriptions into design
    added all part info from original 24well LPA 'Nature' article (Supplementary Information, Table S1).
    part info uses "Description", "Manufacturer1", "MPN1", "Vendor1" and "SKU1" part fields.
    changed part info for new LED parts, and C5,C12 chosen part for new case size.
    changed P2 to 2x3way exact part rather than 40way breakable header.
    changed R15-R19 from 50k to 47k to match part number
    [lpa96.sch, lpa96_leds_drivers.sch]
2019-09-04 updated 3d models & footprint references
    changed P1 and P2 library part models to match part from BOM
    added Molex step model for P1
    fixed U2 SOT223 model to use modern STEP model instead of old .wrl
    updated resistor/capacitor footprints to match KiCAD5 library name changes
    deleted fp-info-cache and added to git ignore (not needed, generated dynamically)
    [Molex_009652028.stp, lpa96.kicad_pcb, lpa96.sch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]
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2019-09-05 re-imported netlist, set U2 pin4 back to VCC net to fix DRCs
    [lpa96.kicad_pcb]
2019-09-05 re-exported files for v2.1 layout
    re-exported gerbers, drill, step, positions, pdfs, images
    ticked box during .pos export to export all SMD parts (SW1 missing before!)
    [lpa96-B_Cu.gbr, lpa96-B_Fab.gbr, lpa96-B_Mask.gbr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]
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2019-09-05 changed column name to digikey and remove supplier/vendor column
    quick fix to hopefully get working
    [lpa96_BOM.tsv]
2019-09-05 Revert "changed column name to digikey and remove supplier/vendor column"
    This reverts commit 9866fa8dc004e1a811d6ab44e84e897f03d9f48f.
    [lpa96_BOM.tsv]
2019-09-05 changed column heading but didn't remove last column as created issue
    [lpa96_BOM.tsv]
